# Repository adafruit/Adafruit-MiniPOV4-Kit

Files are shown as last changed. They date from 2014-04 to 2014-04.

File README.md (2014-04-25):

MiniPOV4-Kit
============

Files, Firmware and Software for the MiniPOV4 color light-painting kit
Pick up a kit here: https://www.adafruit.com/products/1776

The latest and greatest MiniPOV kit to hit the streets - MiniPOV4! We have added full color RGB LEDs to the kit as well USB programmability to make this the easiest, most fun Persistence-of-Vision & Light Painting kit ever.

Learn to solder by building this easy kit. About 30 components are soldered onto the custom PCB using a soldering iron, solder and some basic hand tools such as diagonal cutters and wire strippers. Learn as you go, starting with the easier parts and working your way up to the more challenging ones. Takes about an hour or two to complete following our detailed tutorial, depending on your previous soldering experience. 

* Firmware: The Arduino-IDE compatible firmware that draws images from EEPROM

* Hardware: PCB files in Eagle CAD format

* Images: some test pix we use

* Bootloader: The V-USB based bootloader that lets you program the EEPROM over USB for uploading new images.

* Software: The image uploader, for use with Processing!

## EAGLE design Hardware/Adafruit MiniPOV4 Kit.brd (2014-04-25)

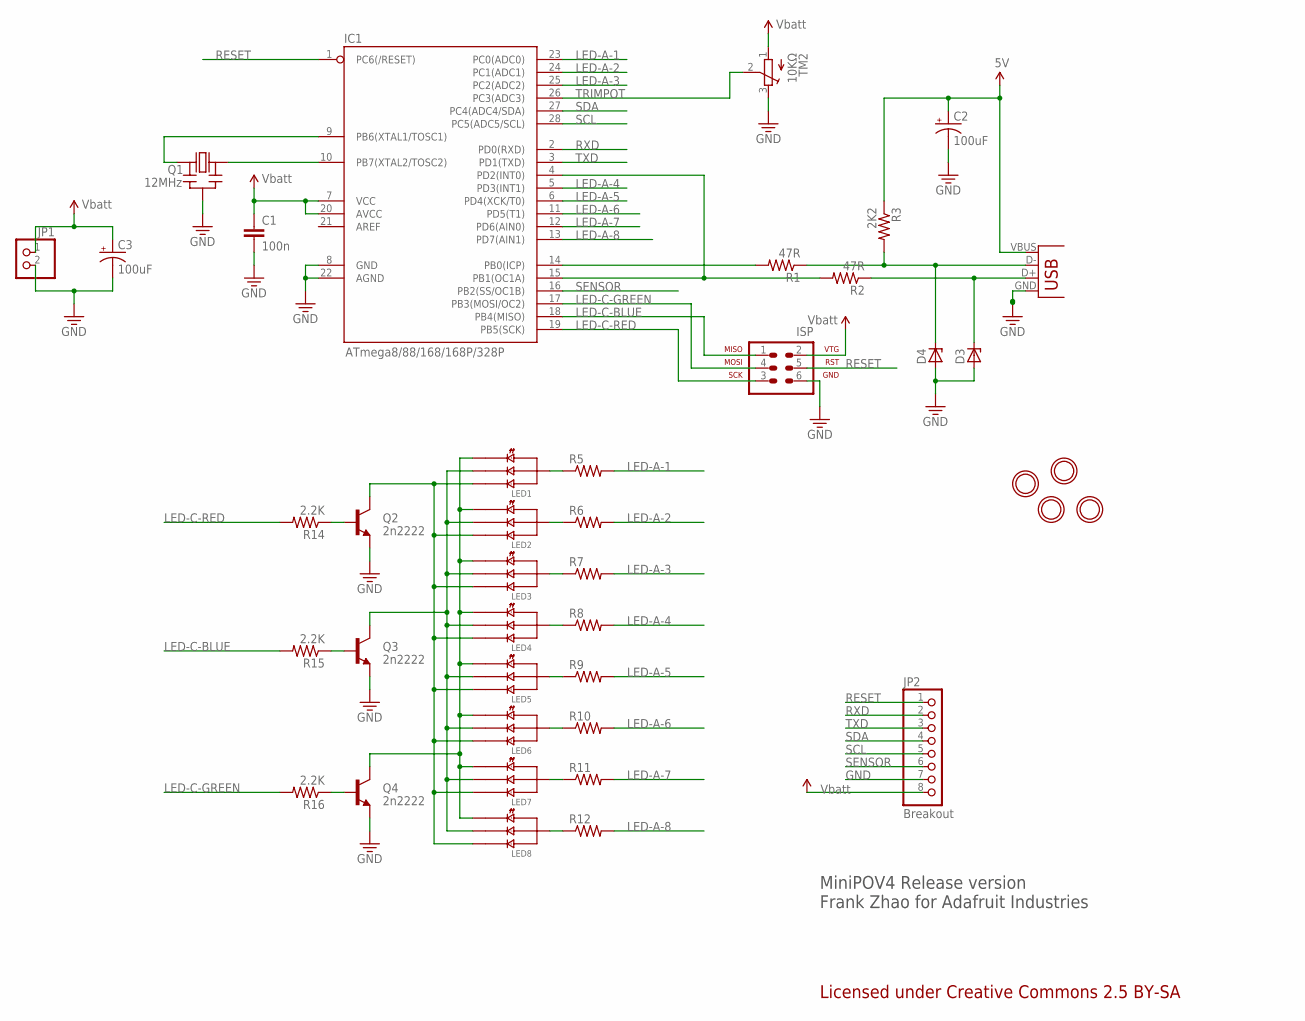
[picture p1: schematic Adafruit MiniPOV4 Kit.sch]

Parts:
C1: 100n; CAP-PTH-SMALL2
C2, C3: 100uF; E2,5-6
D3, D4: ZENER-DIODEDO34-7; DO34Z7
IC1: ATmega8/88/168/168P/328P; DIL28-3
ISP: AVR-ISP-6
JP1: HEADER-1X2; 1X02_OVAL
JP2: Breakout; 1X08-BIG
LED1, LED2, LED3, LED4, LED5, LED6, LED7, LED8: LED-RGB-CA-PIRANHA; PIRANHA5MM
Q1: 12MHz; CERM_OSC
Q2, Q3, Q4: 2n2222; TO-92
R1, R2: 47R; 0207/9
R3: 2K2; 0207/9
R5, R6, R7, R8, R9, R10, R11, R12: R-US_0207/9; 0207/9
R14, R15, R16: 2.2K; 0207/9
TM2: 10KΩ; TRIM-3386
U$2, U$3, U$4, U$5: MOUNTINGHOLE2.5_THICK; MOUNTINGHOLE_2.5_PLATED_THICK
USB: USBPTH; USB-B-PTH

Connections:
3.3V: C1.1, C3.+, IC1.7 (VCC), IC1.20 (AVCC), ISP.2 (VTG), JP1.1, JP2.8, TM2.1 (A)
5V: C2.+, R3.1, USB.VBUS
GND: C1.2, C2.-, C3.-, D3.A, D4.A, IC1.8 (GND), IC1.22 (AGND), ISP.6 (GND), JP1.2, JP2.7, Q1.G (GND), Q2.1 (E), Q3.1 (E), Q4.1 (E), TM2.3 (E), USB.GND, USB.S1, USB.S2
LED-A-1: IC1.23 (PC0(ADC0)), R5.2
LED-A-2: IC1.24 (PC1(ADC1)), R6.2
LED-A-3: IC1.25 (PC2(ADC2)), R7.2
LED-A-4: IC1.5 (PD3(INT1)), R8.2
LED-A-5: IC1.6 (PD4(XCK/T0)), R9.2
LED-A-6: IC1.11 (PD5(T1)), R10.2
LED-A-7: IC1.12 (PD6(AIN0)), R11.2
LED-A-8: IC1.13 (PD7(AIN1)), R12.2
LED-C-BLUE: IC1.18 (PB4(MISO)), ISP.1 (MISO), R15.2
LED-C-GREEN: IC1.17 (PB3(MOSI/OC2)), ISP.4 (MOSI), R16.2
LED-C-RED: IC1.19 (PB5(SCK)), ISP.3 (SCK), R14.2
unnamed: IC1.9 (PB6(XTAL1/TOSC1)), Q1.1 (IN)
unnamed: IC1.10 (PB7(XTAL2/TOSC2)), Q1.2 (OUT)
unnamed: D4.C, R1.1, R3.2, USB.D-
unnamed: D3.C, R2.1, USB.D+
unnamed: LED2.4 (C), R6.1
unnamed: LED1.4 (C), R5.1
unnamed: IC1.14 (PB0(ICP)), R1.2
unnamed: IC1.4 (PD2(INT0)), IC1.15 (PB1(OC1A)), R2.2
unnamed: LED8.4 (C), R12.1
unnamed: LED7.4 (C), R11.1
unnamed: LED6.4 (C), R10.1
unnamed: LED5.4 (C), R9.1
unnamed: LED4.4 (C), R8.1
unnamed: LED3.4 (C), R7.1
unnamed: LED1.2 (R), LED2.2 (R), LED3.2 (R), LED4.2 (R), LED5.2 (R), LED6.2 (R), LED7.2 (R), LED8.2 (R), Q4.3 (C)
unnamed: LED1.3 (G), LED2.3 (G), LED3.3 (G), LED4.3 (G), LED5.3 (G), LED6.3 (G), LED7.3 (G), LED8.3 (G), Q3.3 (C)
unnamed: LED1.1 (B), LED2.1 (B), LED3.1 (B), LED4.1 (B), LED5.1 (B), LED6.1 (B), LED7.1 (B), LED8.1 (B), Q2.3 (C)
unnamed: Q2.2 (B), R14.1
unnamed: Q3.2 (B), R15.1
unnamed: Q4.2 (B), R16.1
RESET: IC1.1 (PC6(/RESET)), ISP.5 (RST), JP2.1
RXD: IC1.2 (PD0(RXD)), JP2.2
SCL: IC1.28 (PC5(ADC5/SCL)), JP2.5
SDA: IC1.27 (PC4(ADC4/SDA)), JP2.4
SENSOR: IC1.16 (PB2(SS/OC1B)), JP2.6
TRIMPOT: IC1.26 (PC3(ADC3)), TM2.2 (S)
TXD: IC1.3 (PD1(TXD)), JP2.3

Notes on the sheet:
MiniPOV4 Release version Frank Zhao for Adafruit Industries
Licensed under Creative Commons 2.5 BY-SA

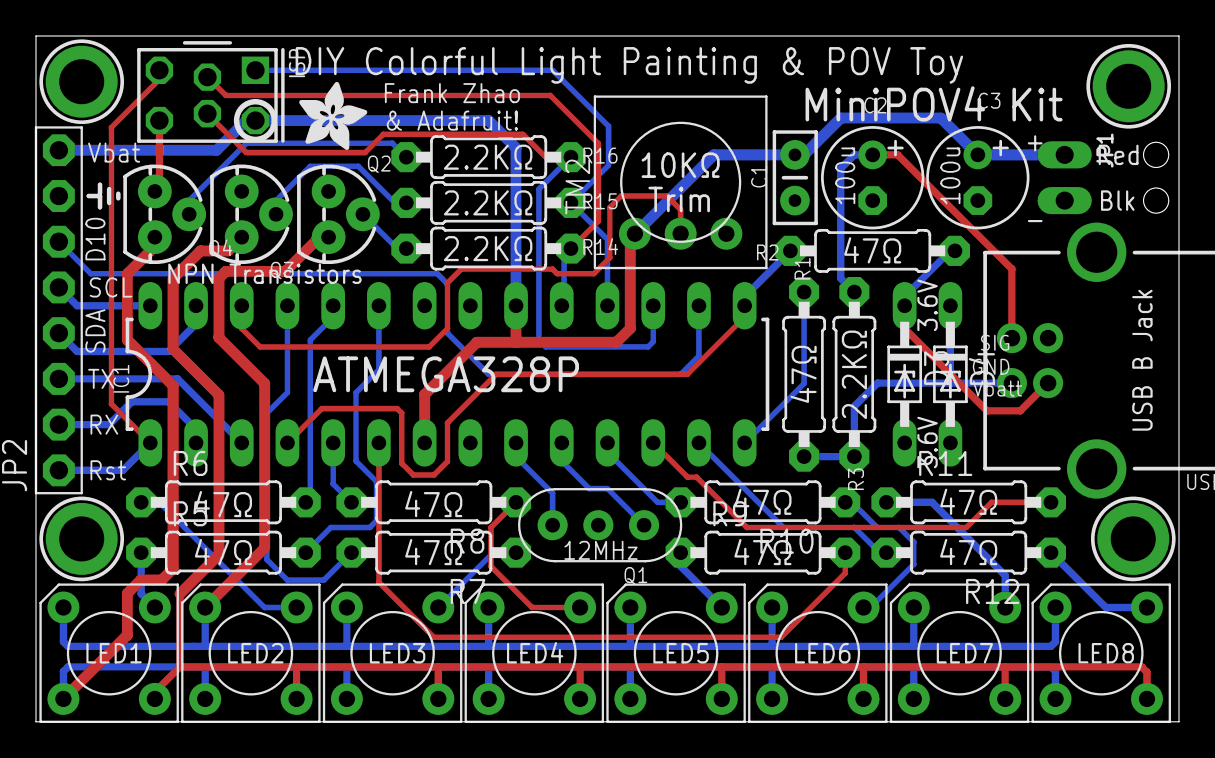
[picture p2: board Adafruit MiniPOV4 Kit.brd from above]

Board: 2 copper layers, 63.5 x 38.1 mm, 42 parts (0 on the bottom side), 41 nets.

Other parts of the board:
U$6: ADAFRUIT_3.5MM

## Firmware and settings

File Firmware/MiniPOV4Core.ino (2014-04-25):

/*
  MiniPOV4 Core firmware, Arduino-esque edition
  Written by Frank Zhao for Adafruit Industries

  Project can be opened with Arduino IDE and programmed via USBtiny bootlader
  by holding down shift while uploading (select USBtinyISP as programmer)

  Licensed under GPL v2
*/

#include <avr/io.h>
#include <avr/eeprom.h>
#include <avr/pgmspace.h>
#include <avr/interrupt.h>
#include <avr/wdt.h>
#include <util/delay.h>
#include "debug.h"

// enable/disable features here
#define ENABLE_USB_DETECT

// how many 'color loops'
#define COLORLOOPS 1

// hardware pin config for higher speeds!
#define LED_CATHODES_DDRx  DDRB
#define LED_CATHODES_PORTx PORTB
#define LED_RED_PINNUM 4
#define LED_GREEN_PINNUM 3
#define LED_BLUE_PINNUM 5

#define LED_8_4_PORTx PORTD
#define LED_3_1_PORTx PORTC

/// arduino pin defines
#define BLUE  13
#define RED   12
#define GREEN 11
#define LED1 A0
#define LED2 A1
#define LED3 A2
#define LED4 3
#define LED5 4
#define LED6 5
#define LED7 6
#define LED8 7
#define TILTSW 10
#define USBDETECT 8

#define MINSPEED 100 // actually, the fastest speed
#define MAXSPEED 1000 // actually, the slowest speed

uint8_t led_anodes[] = {LED1, LED2, LED3, LED4, LED5, LED6, LED7, LED8};
uint8_t led_cathodes[] = {RED, GREEN, BLUE};
////

volatile int ani_length;
volatile int ani_idx;
volatile uint8_t colour_idx = 0; // 0 = R, 1 = G, 2 = B, repeating
volatile uint8_t shade_idx = 0;
volatile byte frame_buffer[8];

int speed = 0;

void setup()
{
  Serial.begin(115200);
  Serial.println("Welcome to MiniPOV 4!");
  
  // pin direction setup
  pinMode(RED, OUTPUT); 
  pinMode(BLUE, OUTPUT); 
  pinMode(GREEN, OUTPUT); 
  
  pinMode(LED8, OUTPUT);
  pinMode(LED7, OUTPUT);
  pinMode(LED6, OUTPUT);
  pinMode(LED5, OUTPUT);
  pinMode(LED4, OUTPUT);
  pinMode(LED3, OUTPUT);
  pinMode(LED2, OUTPUT);
  pinMode(LED1, OUTPUT);

  pinMode(TILTSW, INPUT);
  pinMode(USBDETECT, INPUT);
	
  // setup pull-up resistor
  digitalWrite(TILTSW, HIGH); // TILTSWITCH_PORTx |= _BV(TILTSWITCH_PINNUM);
  
  // default off
  digitalWrite(RED, LOW);
  digitalWrite(BLUE, LOW);;
  digitalWrite(GREEN, LOW); 
  
  digitalWrite(LED1, LOW);
  digitalWrite(LED2, LOW);
  digitalWrite(LED3, LOW);
  digitalWrite(LED4, LOW);
  digitalWrite(LED5, LOW);
  digitalWrite(LED6, LOW);
  digitalWrite(LED7, LOW);
  digitalWrite(LED1, LOW);
  
  digitalWrite(USBDETECT, LOW);
  
  // Strobe all the LEDs (a nice easy test
  for (uint8_t c=0; c<3; c++) {
    // turn on one color at a time
    digitalWrite(led_cathodes[c], HIGH);
    for (uint8_t a=0; a<8; a++) {
      // turn on one LED at a time
      digitalWrite(led_anodes[a], HIGH);
      delay(30);
    }
    // turn it off
    digitalWrite(led_cathodes[c], LOW);
    for (uint8_t a=0; a<8; a++) {
      digitalWrite(led_anodes[a], LOW);
    }
  }

  // check the animation length
  ani_length = (eeprom_read_byte((uint8_t*)0) << 8) + eeprom_read_byte((uint8_t*)1);
  Serial.print("Found a "); Serial.print(ani_length); Serial.println(" byte image");
  
  pinMode(10, OUTPUT);
  
  speed = analogRead(3);
  Serial.print("Setting speed to "); Serial.println(speed);  
  // start timer
  TCCR1A = 0;
  TCCR1B = _BV(WGM12) | 0x05;
  OCR1A = map(speed, 0, 1024, MINSPEED, MAXSPEED); // this should not be lower than 500
  TIMSK1 |= _BV(OCIE1A);   // Output Compare Interrupt Enable (timer 1, OCR1A)
}

void loop()
{
  // it might seem strange that nothing important happens in this loop
  // but it is because timer1's ISR is handling all the LED lighting
  // with extreme timing precision
  // this allows us to implement 8 bit color PWM shading

#ifdef ENABLE_USB_DETECT
  // if USB connection detected, reset and jump to bootloader
  if (digitalRead(USBDETECT)) {
    wdt_enable(WDTO_15MS); // force watchdog reset
    while (1);
  }
#endif // ENABLE_USB_DETECT

  if ( abs(speed - analogRead(3)) > 5) {
    speed = analogRead(3);
    Serial.print("Setting speed to "); Serial.println(speed);  
    OCR1A = map(speed, 0, 1024, MINSPEED, MAXSPEED);
  }
}

ISR(TIMER1_COMPA_vect)
{
  PORTB |= _BV(2);
  // show the next frame
  // data format is
  // 0bRRRGGGBB, eight of them
  uint8_t i, b, cathodeport = 0, ledport = 0;
   
  // We use direct port access is used instead of Arduino-style
  // because this needs to be fast
     
  if (colour_idx == 0) {
    cathodeport = _BV(LED_RED_PINNUM);

    for (i = 0; i < 8; i++) {
      b = (frame_buffer[i] & 0xE0) >> 5;
      if (b > shade_idx)
        ledport |= _BV(i); 
    }
  }
  else if (colour_idx == 1)
  {
    cathodeport = _BV(LED_GREEN_PINNUM);
    
    for (i = 0; i < 8; i++) {
      b = (frame_buffer[i] & 0x1C) >> 2;
      if (b > shade_idx)
        ledport |= _BV(i);
    }
  }
  else if (colour_idx == 2)
  {
    cathodeport = _BV(LED_BLUE_PINNUM);
  
    uint8_t s = shade_idx >> 1;

    for (i = 0; i < 8; i++) {
      b = frame_buffer[i] & 0x03;
      if (b > s)
        ledport |= _BV(i); 
    }
  }
  PRINT_F("\n\rLEDport = "); DEBUGPRINT_HEX(ledport);
  PRINT_F("\tcathodes = "); DEBUGPRINT_HEX(cathodeport);
  LED_3_1_PORTx &= ~(0x07);
  LED_8_4_PORTx &= ~(0xF8);
  LED_CATHODES_PORTx &= ~_BV(LED_RED_PINNUM) & ~_BV(LED_GREEN_PINNUM) & ~_BV(LED_BLUE_PINNUM);
  LED_3_1_PORTx |= ledport & 0x7;
  LED_8_4_PORTx |= ledport & 0xF8;
  LED_CATHODES_PORTx |= cathodeport;

  // next color
  colour_idx++;
  if (colour_idx >= 3) {
    colour_idx = 0;
    shade_idx++;
    if (shade_idx >= 7) {
      shade_idx = 0;
      PRINT_F("New Pixel: ");
      // simple next frame with roll over
      ani_idx++;
      if (ani_idx >= ani_length) {
        ani_idx = 0;
      }
      eeprom_read_block((void*)frame_buffer, (const void*)(2 + (ani_idx * 8)), 8); // load next frame
      for (uint8_t p=0; p<8; p++) {
        DEBUGPRINT_HEX(frame_buffer[p]);
        PRINT_F(", ");
      }
    }
  }
  PORTB &= ~_BV(2);
}

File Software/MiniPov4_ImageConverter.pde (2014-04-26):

/*
Image Converter for MiniPOV4
by Frank Zhao

requires Processing 2.0, and the library controlP5 2.0.4 (or later) to be installed
also requires avrdude 5.11 or later, installed somewhere that can be called directly

version 201306111447:
  * 8 bit shading added
  * fixed image disappearing upon resize
  * TODO: implement size limit, I am waiting for the hardware to be finalized
version 201306101727:
  * no upscaling from images smaller than 80pix high
version 201306101542:
  * almost all basic functionality works
  * shading not supported, so 3 bit color only
  
*/

import controlP5.*;
import javax.swing.*; 
import javax.swing.filechooser.*;
import java.awt.image.*;
import javax.imageio.*;
import java.io.*;
import java.util.prefs.*;
import java.awt.event.*;

ControlP5 cp5;
Preferences prefs;
boolean cp5_isReady = false;
PImage img1, img2;
int imgW;
boolean need_redraw = false;

void setup()
{
  // helps the file dialogs remember the last directory
  prefs = Preferences.userNodeForPackage(this.getClass());
  
  // this makes the file dialogs look pretty
  try { 
    UIManager.setLookAndFeel(UIManager.getSystemLookAndFeelClassName()); 
  } catch (Exception e) { 
    e.printStackTrace();
  } 

  size(800, 190);
  if (frame != null) {
    frame.setResizable(true);
  }
  
  background(0, 0, 0);
  
  cp5 = new ControlP5(this);
  
  int x = 10;
  int yStart = 10;
  int ySpace = 20;
  int w = 120;
  
  cp5.addButton("openImg")
   .setLabel("Open Image File")
   .setValue(0)
   .setPosition(x, yStart + (ySpace * 0))
   .setSize(w, ySpace - 1)
   ;
   
  cp5.addButton("saveBin")
   .setLabel("Save as BIN File")
   .setValue(0)
   .setPosition(x, yStart + (ySpace * 1))
   .setSize(w, ySpace - 1)
   ;
   
  cp5.addButton("openBin")
   .setLabel("Open BIN File")
   .setValue(0)
   .setPosition(x, yStart + (ySpace * 2))
   .setSize(w, ySpace - 1)
   ;
   
  cp5.addButton("download")
   .setLabel("Download to MiniPOV4")
   .setValue(0)
   .setPosition(x, yStart + (ySpace * 3))
   .setSize(w, ySpace - 1)
   ;
  
  println("ready");
  
  // this version of controlP5 seems to call the events when the buttons are created, so I have a flag here to prevent that
  cp5_isReady = true;
  
  // resizing the window seems to erase the image, so we detect this event and redraw later 
  frame.addComponentListener(new ComponentAdapter()
  {
    public void componentResized(ComponentEvent e)
    {
      if(e.getSource() == frame) {
        need_redraw = true;
      }
    }
  }); 
}

void draw()
{
  if (need_redraw) {
    // resizing the window seems to erase the image, so we detect this event and redraw later
    if (img1 != null) image(img1, 10 + 120 + 10, 10);
    if (img2 != null) image(img2, 10 + 120 + 10, 10 + 80 + 10);
    need_redraw = false;
  }
}

// this mode only supports 3 bit, so only on and off for each color
color colorDownConvert3(color c)
{
  // extract the individual channels
  int cred = c >> 16 & 0xFF;
  int cgreen = c >> 8 & 0xFF;
  int cblue = c >> 0 & 0xFF;
  
  // do color conversion here
  if (cred > 0x7F) cred = 0xFF; else cred = 0x00;
  if (cgreen > 0x7F) cgreen = 0xFF; else cgreen = 0x00;
  if (cblue > 0x7F) cblue = 0xFF; else cblue = 0x00;
        
  return color(cred, cgreen, cblue);
}

// this mode supports 8 bit shading
color colorDownConvert8(color c)
{
  // extract the individual channels
  int cred = c >> 16 & 0xFF;
  int cgreen = c >> 8 & 0xFF;
  int cblue = c >> 0 & 0xFF;
  
  // do color conversion here
 cred = cred & 0xE0;
 cgreen = cgreen & 0xE0;
 cblue = cblue & 0xC0;
 if (cred == 0xE0) cred = 0xFF;
 if (cgreen == 0xE0) cgreen = 0xFF;
 if (cblue == 0xC0) cblue = 0xFF;
        
  return color(cred, cgreen, cblue);
}

color colorDownConvert(color c)
{
  // change the default conversion mode here
  return colorDownConvert8(c);
}

byte colorToByte(color c)
{
  // extract the individual channels
  int cred = c >> 16 & 0xFF;
  int cgreen = c >> 8 & 0xFF;
  int cblue = c >> 0 & 0xFF;
  
  byte b = 0;
  
  b += cred & 0xE0;
  b += cgreen >> 3 & 0x1C;
  b += cblue >> 6 & 0x03;
  
  return b;
}

color byteToColor(byte b)
{
  int cred, cgreen, cblue;
  cred = b & 0xE0;
  if (cred >= 0xE0) cred = 0xFF;
  cgreen = (b & 0x1C) << 3;
  if (cgreen >= 0xE0) cgreen = 0xFF;
  cblue = (b & 0x03) << 6;
  if (cblue >= 0xC0) cblue = 0xFF;  
  return color(cred, cgreen, cblue);
}

public void openImg(int val)
{
  if (!cp5_isReady) return;
  
  println("openImg clicked");
  
  final JFileChooser fc = new JFileChooser(); 
  println("Chooser");
  
  try {
    fc.setCurrentDirectory(new File(prefs.get("LAST_FILECHOOSER_DIR", "")));
    println("set CD");
  } catch (Exception e) { 
    e.printStackTrace();
  }
  
  fc.addChoosableFileFilter(new FileNameExtensionFilter("Image Files", ImageIO.getReaderFileSuffixes()));
  println("ChoosableFilter");
  
  if (fc.showOpenDialog(this) == JFileChooser.APPROVE_OPTION)
  {
      println("Approved");
    String fp = fc.getSelectedFile().getPath();
    println("file: " + fp);
    
    prefs.put("LAST_FILECHOOSER_DIR", fc.getSelectedFile().getParent());
    
    background(0);
    
    try {
      // generate preview
      img1 = loadImage(fp);
      int w, h;
      w = img1.width;
      h = img1.height;
      float scale = 80.0f / h;
      int nw = round(w * scale);
      if (scale < 1.0f) {
        img1.resize(nw, 80);
      }
      image(img1, 10 + 120 + 10, 10);
      
      // down convert to 8 pixel high
      PImage si = loadImage(fp);
      scale = 8.0f / h;
      imgW = round(w * scale);
      si.resize(imgW, 8);
      si.loadPixels();
      img2 = new PImage(nw, 80);
      
      // convert for preview
      for (int x = 0; x < nw; x++)
      {
        for (int y = 0; y < 80; y++)
        {
          color c = si.get(floor(x / 10.0f), floor(y / 10.0f));        
          img2.set(x, y, colorDownConvert(c));
        }
      }
      
      image(img2, 10 + 120 + 10, 10 + 80 + 10);
    }
    catch (Exception e) {
      e.printStackTrace();
      JOptionPane.showMessageDialog(null, "Error while loading image: " + e.getMessage());
    }
  } else {
      println("???");
  }
}

boolean saveToBin(String fp)
{
  if (img2 == null) {
    JOptionPane.showMessageDialog(null, "Error: No Image Loaded");
    return false;
  }
  
  try {
    FileOutputStream fstream = new FileOutputStream(fp);
    BufferedOutputStream bstream = new BufferedOutputStream(fstream);
    DataOutputStream dstream = new DataOutputStream(bstream);
    
    // first 2 bytes indicate size
    dstream.writeShort(imgW);
    for (int x = 0; x < imgW; x++)
    {
      for (int y = 0; y < 8; y++)
      {
        color c = img2.get(x * 10, y * 10);
        byte b = colorToByte(c);
        dstream.writeByte(b);
      }
    }
    
    dstream.close();
    bstream.close();
    fstream.close();
    return true;
  }
  catch (Exception e) {
    e.printStackTrace();
    JOptionPane.showMessageDialog(null, "Error while writing file: " + e.getMessage());
    return false;
  }
}
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

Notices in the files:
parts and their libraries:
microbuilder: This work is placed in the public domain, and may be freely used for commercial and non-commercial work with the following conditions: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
